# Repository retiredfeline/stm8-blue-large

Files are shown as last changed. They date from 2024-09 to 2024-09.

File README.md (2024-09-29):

## Large STM8S103F3P6 development board

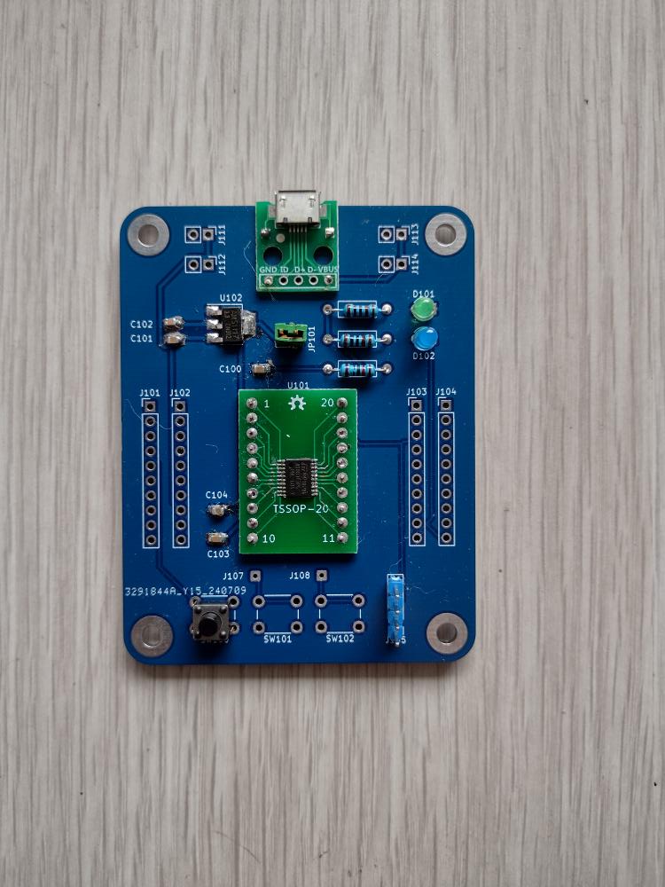
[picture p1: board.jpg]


This is a large version of the STM8 "Blue Pill", not to be confused with the STM32 "Blue Pill". I designed this mainly to get more connection points: 2 header pads for each STM8 pin, 4 sets of power supply headers for connecting peripherals, and 2 uncommitted tactile button positions. Small size wasn't important to me; I wanted something to build gadgets using the STM8S103F3P6 chips I had.

The jumper bridge between +5v ad +3.3V is used when you want to run the MCU at 5V, perhaps to connect to 5V peripherals. For downloading the firmware to the MCU, the STlink dongle will provide 3.3V. Do not connect both the dongle and the micro-USB power at the same time.

This is a mixed design. The capacitors are SMT while the resistors and LEDs are THT; they were what I had handy. The micro-USB connector is an adaptor you can buy from the usual outlets for easier soldering. The MCU footprint is hybrid: there are TSSOP-20 pads but also 20 THT pads for an adaptor board so that you or a skilled friend can solder that separately.

Thus I don't expect that the design will suit everybody or even anybody as is, but I'm publishing it so that people can have KiCad design info to remix into their own design.

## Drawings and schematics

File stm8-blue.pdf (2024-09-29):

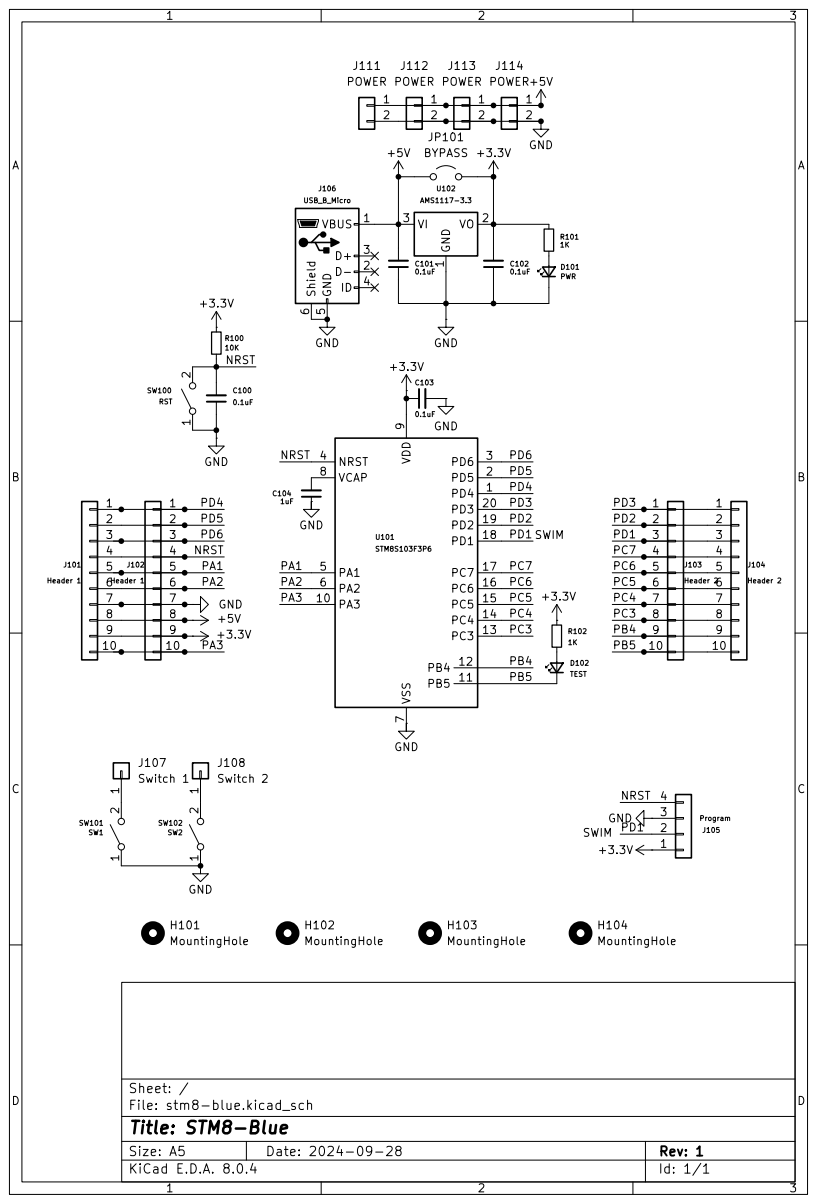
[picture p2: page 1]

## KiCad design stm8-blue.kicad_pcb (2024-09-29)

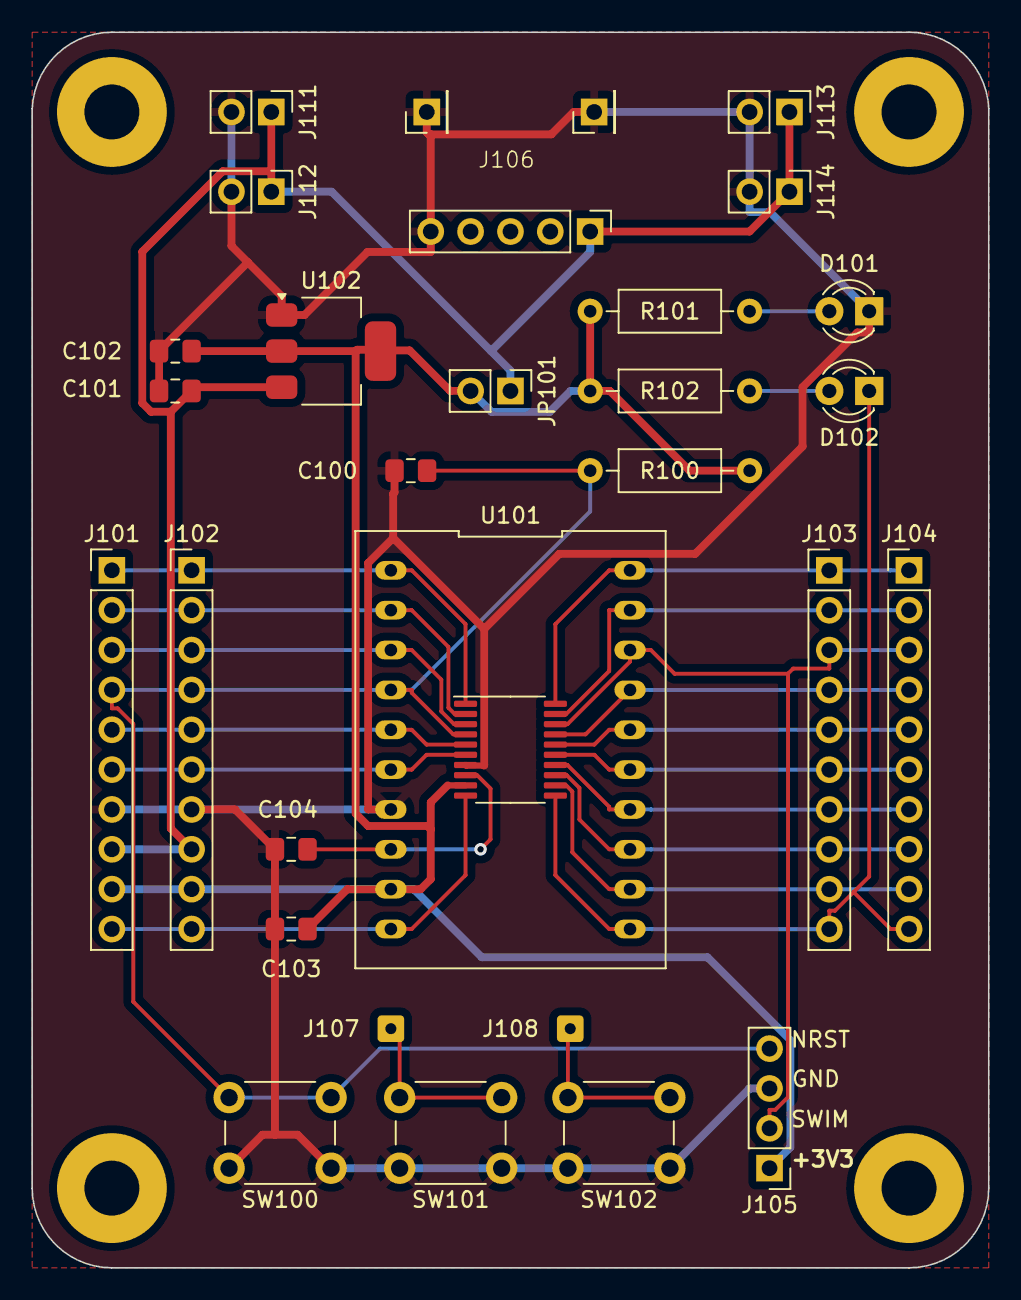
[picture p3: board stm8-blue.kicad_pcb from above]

Board: 2 copper layers, 61.0 x 78.7 mm, 32 parts (0 on the bottom side), 25 nets.

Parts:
C100, C101, C102, C103: 0.1uF; C_0805_2012Metric_Pad1.18x1.45mm_HandSolder
C104: 1uF; C_0805_2012Metric_Pad1.18x1.45mm_HandSolder
D101: PWR; LED_D3.0mm
D102: TEST; LED_D3.0mm
H101, H102, H103, H104: MountingHole; MountingHole_3.5mm_Pad
J101, J102: Header 1; PinHeader_1x10_P2.54mm_Vertical
J103, J104: Header 2; PinHeader_1x10_P2.54mm_Vertical
J105: Program; PinHeader_1x04_P2.54mm_Vertical
J106: USB_B_Micro; USB Micro power
J107: Switch 1; SolderWire-0.127sqmm_1x01_D0.48mm_OD1mm
J108: Switch 2; SolderWire-0.127sqmm_1x01_D0.48mm_OD1mm
J111, J112, J113, J114: POWER; PinHeader_1x02_P2.54mm_Vertical
JP101: BYPASS; PinHeader_1x02_P2.54mm_Vertical
R100: 10K; R_Axial_DIN0207_L6.3mm_D2.5mm_P10.16mm_Horizontal
R101, R102: 1K; R_Axial_DIN0207_L6.3mm_D2.5mm_P10.16mm_Horizontal
SW100: RST; SW_PUSH_6mm_H5mm
SW101: SW1; SW_PUSH_6mm_H5mm
SW102: SW2; SW_PUSH_6mm_H5mm
U101: STM8S103F3P6; DIP_TSSOP-20_600_ELL
U102: AMS1117-3.3; SOT-223-3_TabPin2

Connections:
+3.3V: C102.2, C103.1, J101.9, J102.9, J105.1, JP101.2 (B), R100.2, R101.1, R102.2, U101.9 (VDD), U102.2 (VO)
+5V: C101.2, J101.8, J102.8, J106.1 (VBUS), J111.1, J112.1, J113.1, J114.1, JP101.1 (A), U102.3 (VI)
/NRST: C100.2, J101.4, J102.4, J105.4, R100.1, SW100.2 (B), U101.4 (NRST)
/PA1: J101.5, J102.5, U101.5 (PA1)
/PA2: J101.6, J102.6, U101.6 (PA2)
/PA3: J101.10, J102.10, U101.10 (PA3)
/PB4: J103.9, J104.9, U101.12 (PB4)
/PB5: D102.1 (K), J103.10, J104.10, U101.11 (PB5)
/PC3: J103.8, J104.8, U101.13 (PC3)
/PC4: J103.7, J104.7, U101.14 (PC4)
/PC5: J103.6, J104.6, U101.15 (PC5)
/PC6: J103.5, J104.5, U101.16 (PC6)
/PC7: J103.4, J104.4, U101.17 (PC7)
/PD1: J103.3, J104.3, J105.2, U101.18 (PD1)
/PD2: J103.2, J104.2, U101.19 (PD2)
/PD3: J103.1, J104.1, U101.20 (PD3)
/PD4: J101.1, J102.1, U101.1 (PD4)
/PD5: J101.2, J102.2, U101.2 (PD5)
/PD6: J101.3, J102.3, U101.3 (PD6)
GND: C100.1, C101.1, C102.1, C103.2, C104.1, D101.1 (K), J101.7, J102.7, J105.3, J106.5 (GND), J106.6 (Shield), J111.2, J112.2, J113.2, J114.2, SW100.1 (A), SW101.1 (A), SW102.1 (A), U101.7 (VSS), U102.1 (GND)
unnamed: D101.2 (A), R101.2
unnamed: D102.2 (A), R102.1
unnamed: J107.1, SW101.2 (B)
unnamed: J108.1, SW102.2 (B)
unnamed: C104.2, U101.8 (VCAP)
